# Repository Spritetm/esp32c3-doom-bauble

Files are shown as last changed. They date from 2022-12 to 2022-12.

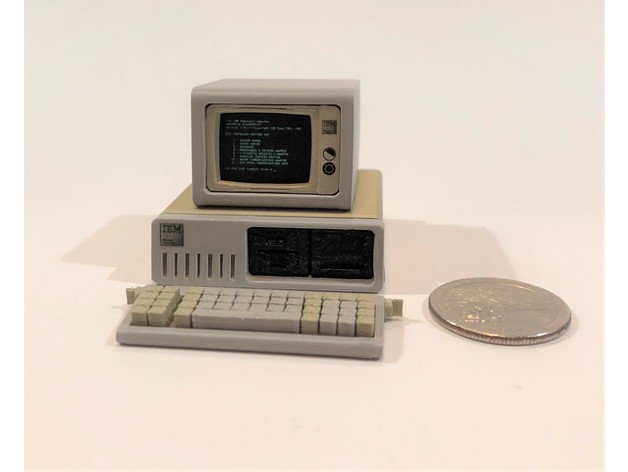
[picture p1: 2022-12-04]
case/images/pc2.jpg

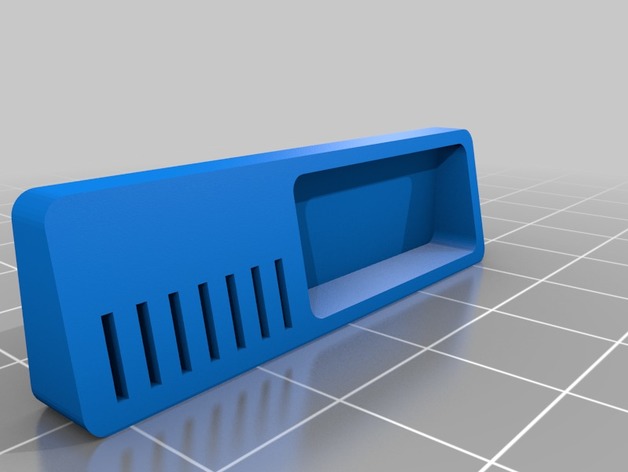
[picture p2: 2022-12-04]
case/images/01515c6048c02ab28ac9dbbb1aa9e8ba.png

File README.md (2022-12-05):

Doom on an ESP32-C3 based Christmas tree bauble
===============================================

This uses the GBA Doom from https://github.com/doomhack/GBADoom to put Doom on a tiny Christmas
bauble. More information is on https://spritesmods.com/?art=doom-bauble .

Directories
-----------

- case: contains OpenSCAD case designs. 
- esp32c3-doom: Contains the firmware. This needs ESP-IDF 5.0 or higher to compile.
- pcb - KiCad PCB designs

Case
----

You should be able to print the case on a FDM ('hot plastic squirter'-type) machine, 
but it'll look better when printed on a SLA/LCD/DLP ('ultra-violet goo hardener'-type)
printer. I masked it with masking tape afterwards and painted it with model paint
(specifically Tamiya TS-81 and TS-06 rattle-can paint).

PCB
---
The PCB designs and schematics are in Kicad format. Look at the schematics for hints 
for components not on the BOM. Note that the 'headers' on the PCB are supposed to have
wires directly soldered to it; space doesn't really allow for actual headers.

Firmware
--------

To build this, you need esp-idf 5.0 or higher. (I used git commit 4c1ff6016a, for reference.) You
also need to make sure you have 8MiB or more flash on your ESP32C3. You can use the standard 
esp-idf building & flashing procedure ('idf.py flash'). Note that you also need to flash the Doom
WAD to the flash. The flash-doom-wad.sh shellscript gives an example on how to do that with the
included doom1gba.wad file; using this will give you the shareware version of Doom (which includes
all the levels of Episode 1).

It is possible to use a different Doom WAD as a basis for this, but you need to manually convert 
it first. Tools and information for that is in the esp32c3-doom/GbaWadUtil. Most importantly, you
probably want to convert any music to IMF format and re-record demos before running GbaWadUtil
to generate the final WAD to be flashed.

Note that this Doom version is not compatible with demos that are included in existing WAD files; 
while they will play, they will likely desync early on. As such, you may want to re-record the
demo files. There's a rudimentary setup for this in esp32c3-doom/main/sdl which can be used to
compile this version of Doom for SDL input and output. After that, you can edit d_main.c and
recompile to enable demo recording of one map.

Note on input devices
---------------------

The ESP32C3 will connect to any BT-LE device that supports HID and is set to pairing mode. 
BT Classic devices aren't supported nor detected. Do note that connecting to an input 
device is not fast. Wait about 10 seconds after putting a device into pairing mode before 
using it.

Joystick has been tested and seems to work OK (although the input is digital only, no analog
movement is supported)

Mouse works, but again: inputs get flattened to digital-only. You may need a mouse 
with >=3 buttons to start the game (mouse wheel press / middle button = start)

Keyboard is implemented but entirely untested. The keymapping should be: z and x for 
shoot & open, a and s for left and right strafe, tab for select, enter for start, cursor 
keys for movement.

In general: weapon selection is hold open + use the strafe keys.

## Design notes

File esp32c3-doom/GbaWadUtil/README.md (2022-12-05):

NOTE: This has been modified for the ESP32C3 version of Doom.

Changes are that demos are replaced by the files in the 'demo' directory, and the original .mus music is replaced by the .imf equivalent in the 'music' directory.

-Sprite_tm

Original README.md:

Utility to process Doom IWAD files for GBA Doom.

It can write either a new WAD file and/or a C Source file.

This is required to reduce the memory footprint of some of the data structures in Doom to get it to fit in 256Kb.

We will pre-calculate more fields so that the lumps stored in the WAD can be used directly from the ROM rather than having to load and convert them in memory.

For example:

In the WAD file a vertex is stored as two short values. (X and Y). When it is loaded into memory, it is shifted left by 16 to convert to 16.16 fixed point. By re-writing this lump and storing it in fixed point, we do not need to copy this into memory at runtime.

Usage: GbaWadUtil -in iwad_file_path -out gba_iwad_path -cfile iwad_cfile_path.

I plan to add PWAD support so that an IWAD and 1 or more PWADS can be converted to a GBA IWAD.

It is a command line util so it can be integrated into a build process.

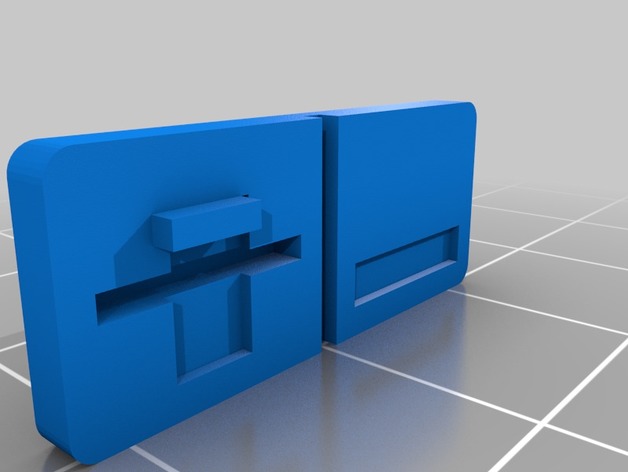
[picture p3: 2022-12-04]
case/images/93f6f09fe746f902d7aaf3ea04f6aa66.png

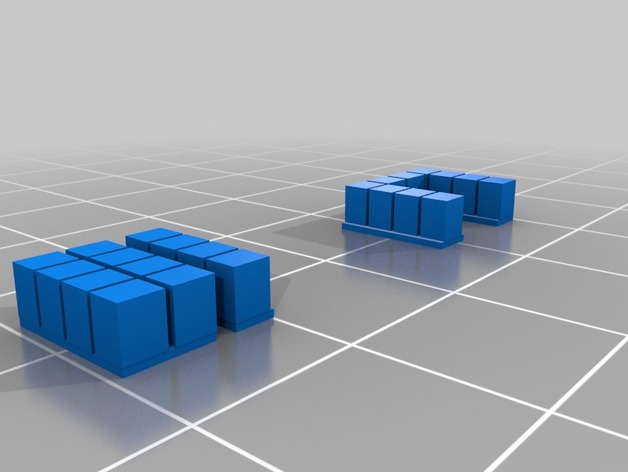
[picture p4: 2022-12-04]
case/images/9a2a5ed90a3d22a2ef03c760bfe90082.png

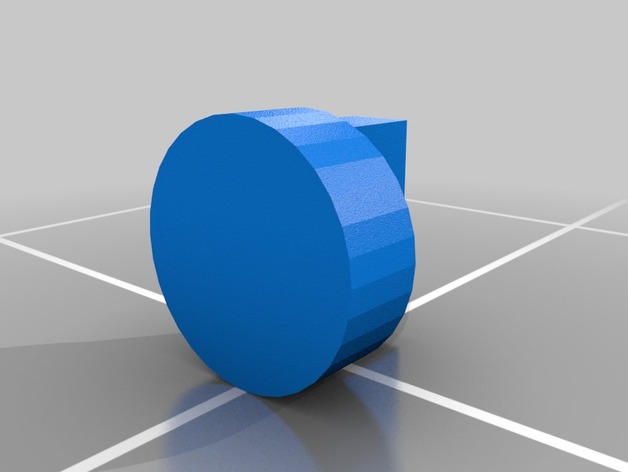
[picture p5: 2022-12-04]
case/images/41cfcd7241238f3be73395aaca2209b7.png

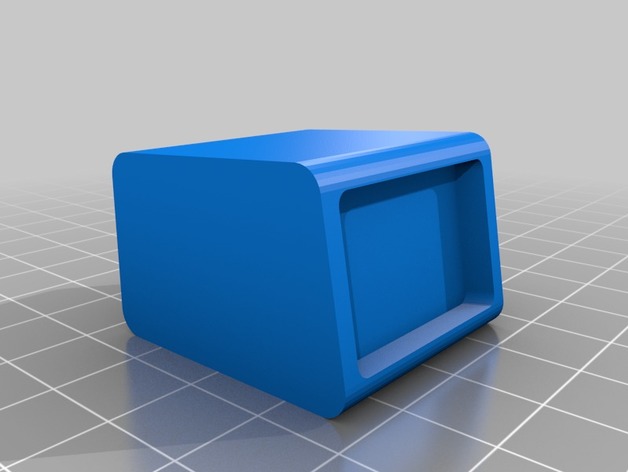
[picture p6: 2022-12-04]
case/images/0346f1c2d8671cf0db3fd7e91bc719b4.png

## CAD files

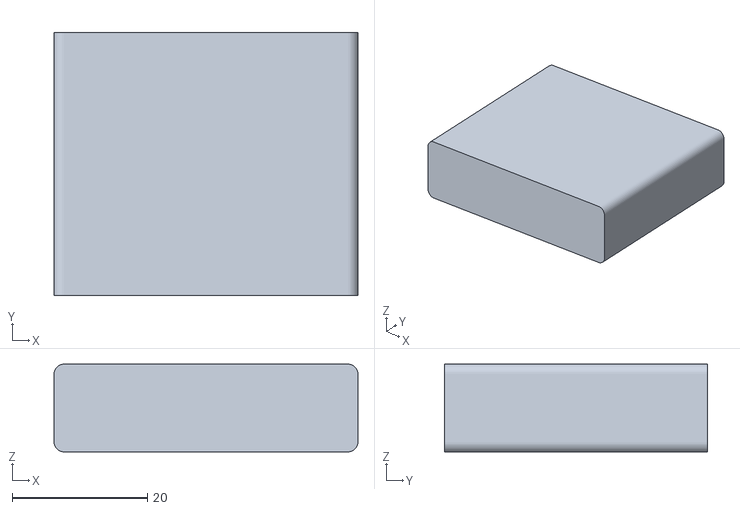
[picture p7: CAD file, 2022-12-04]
case/files/body_back.stl
45.0 x 39.0 x 13.0

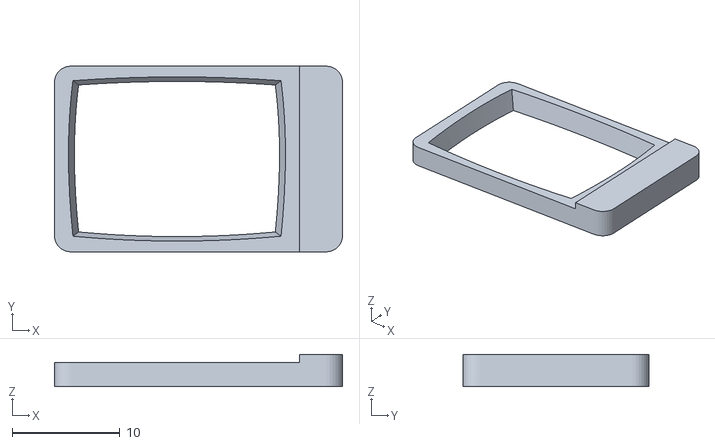
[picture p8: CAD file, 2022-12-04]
case/files/monitor_face.stl
26.8 x 17.2 x 3.00

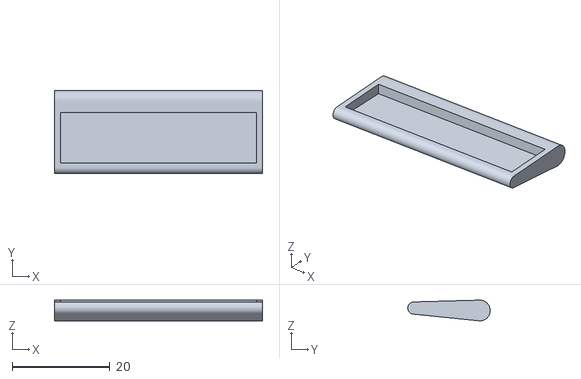
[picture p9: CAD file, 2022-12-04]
case/files/keyboard.stl
42.5 x 16.9 x 4.25

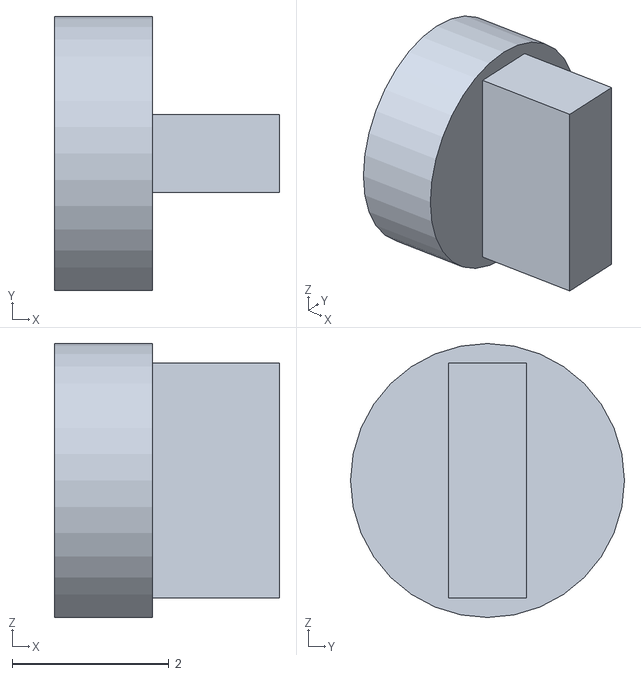
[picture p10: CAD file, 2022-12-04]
case/files/keyboard_post.stl
2.88 x 3.50 x 3.50

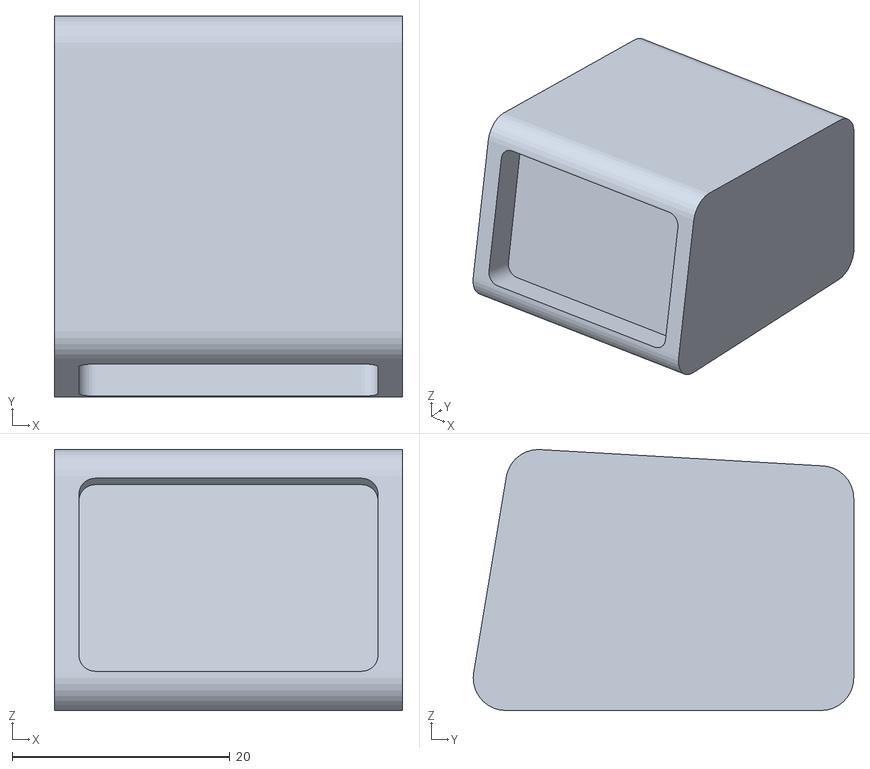
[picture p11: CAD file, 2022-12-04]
case/files/monitor.stl
32.0 x 35.0 x 24.0

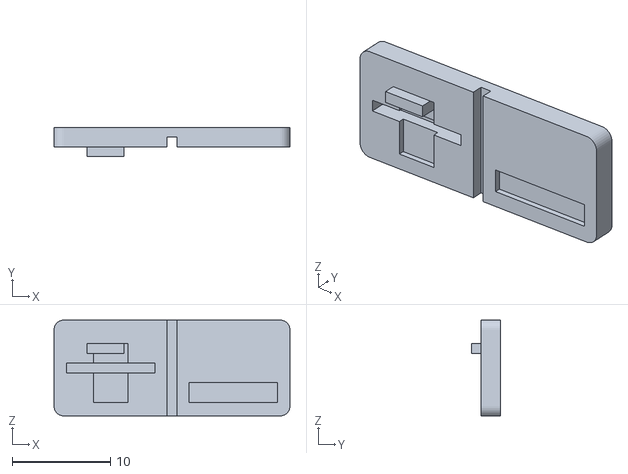
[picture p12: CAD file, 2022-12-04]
case/files/disks.stl
24.0 x 3.00 x 9.75

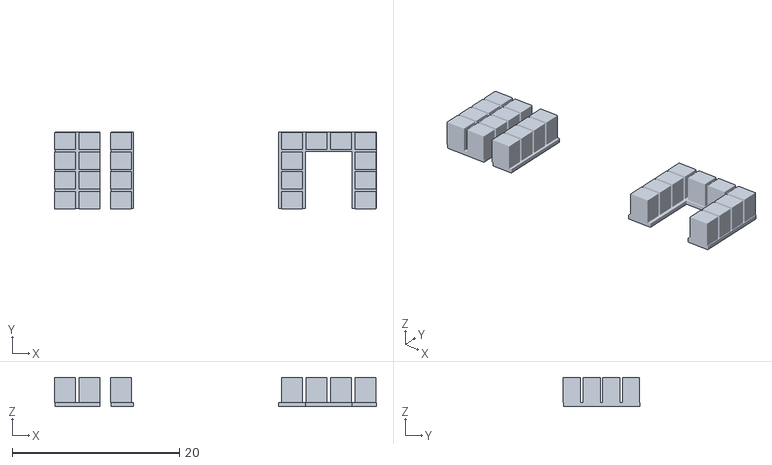
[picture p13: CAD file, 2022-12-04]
case/files/keys_grey.stl
38.5 x 9.17 x 3.50

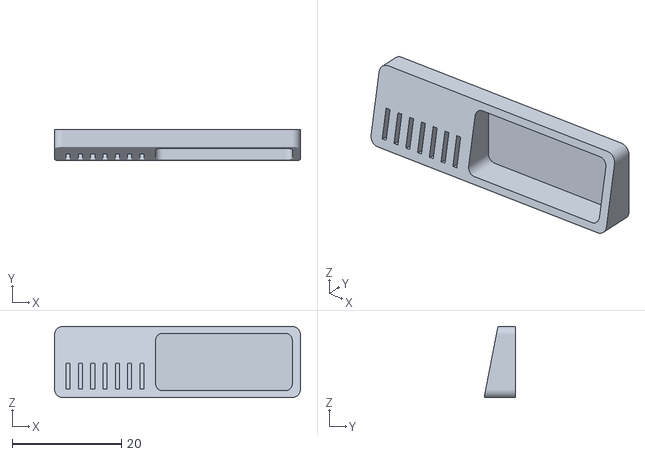
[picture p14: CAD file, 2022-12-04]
case/files/body_face.stl
45.0 x 5.75 x 13.0

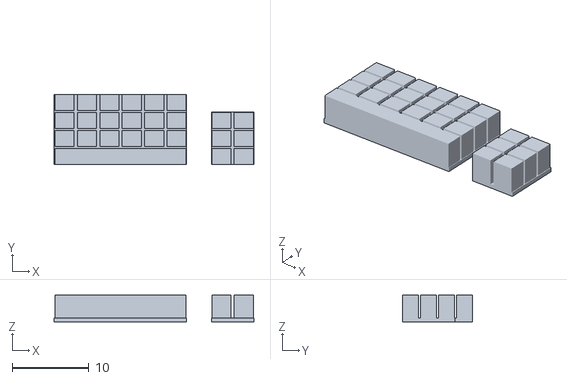
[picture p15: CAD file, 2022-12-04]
case/files/keys_white.stl
26.1 x 9.17 x 3.50

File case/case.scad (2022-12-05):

/*
 * ----------------------------------------------------------------------------
 * "THE BEER-WARE LICENSE" (Revision 42):
 * Jeroen Domburg <jeroen@spritesmods.com> wrote this file. As long as you retain 
 * this notice you can do whatever you want with this stuff. If we meet some day, 
 * and you think this stuff is worth it, you can buy me a beer in return. 
 * ----------------------------------------------------------------------------
 */

//Note that this is based on a design from RabbitEngineering: 
//https://www.thingiverse.com/thing:3331061 which is licensed under CC-BY-NC.
//Files for that are located in the files/ and images/ subdirectory. You will 
//be bound to his license (=no commercial products) as long as you use his STLs.

disp_sz=[28,13.5, 1.5];

$fa=10;
$fs=0.1;

//Enable for the main PC model
pc_model();
//Enable for the bottom plate
//translate([0,0,-3]) bot_plate();

module pokey() {
    translate([0,0,.5+0.7]) sphere(d=1.8);
    cylinder(d=1.5, h=.5+.7);
}

module bot_plate() {
    hull() {
        translate([12,12.5,-.1]) cylinder(h=0.5, d=5);
        translate([-12,12.5,-.1]) cylinder(h=0.5, d=5);
        translate([12,-11,-.1]) cylinder(h=0.5, d=5);
        translate([-12,-11,-.1]) cylinder(h=0.5, d=5);
    }
    translate([12,10,-.1]) pokey();
    translate([-12,10,-.1]) pokey();
    translate([12,-10,-.1]) pokey();
    translate([-12,-10,-.1]) pokey();

}

module pc_model() {
    difference() {
        pc();
        //lcd
    translate([5.2,-11,1]) rotate([-8,0,0]) rotate([90,-90,0]) translate([-3,0,0])cube(disp_sz+[3.2, 0.2, 0.2]);    
        //hollow out
        scale(0.73) translate([0,-0,-0.1]) cube([26,20,70], center=true);
        //air/wire line
        translate([-0.5-5,-12,-0.1]) cube([1,100,1]);
        //switch
        translate([-4.1-5, 10+1.2, -10+2])cube([8.2, 3, 10]);
        translate([-3-5, 10, -10+2])cube([6, 4.2, 10]);
        //switch pokey bit
        translate([-1.7-5, 13, -10+2])cube([3.4, 4.2, 10]);
        //usb conn
        translate([-4.1+5, 9, -10+3])cube([8.2, 7, 10]);
        //usb line
        translate([-1+5, 7, -10+1])cube([2, 7, 10]);
        //usb conn holes
        translate([5,15-1.5, -10+3-2+5]) union() {
            translate([-2.2,0,5]) cube([0.5, 1.2, 10], center=true);
            translate([2.2,0,5]) cube([0.5, 1.2, 10], center=true);
        }
        //speaker grille
        translate([7,-4,4.1]) rotate([0,90,0]) union() {
            for(i=[0:45:360]) {
                rotate([0,0,i]) translate([0,-2.3,0]) cylinder(d=1.2, h=10);
            }
            translate([0,0,0]) cylinder(d=1.2, h=10);
        }
        //speaker
        translate([4.5,-4,4.1]) hull() {
            rotate([0,90,0]) cylinder(d=8.1, h=10);
            translate([0,0,-8]) rotate([0,90,0])  cylinder(d=8.1, h=10);
        }
        //holes for bottom plate
        translate([12,10,-.1]) cylinder(h=2, d1=1.8, d2=2.1);
        translate([-12,10,-.1]) cylinder(h=2, d1=1.8, d2=2.1);
        translate([12,-10,-.1]) cylinder(h=2, d1=1.8, d2=2.1);
        translate([-12,-10,-.1]) cylinder(h=2, d1=1.8, d2=2.1);
        //cut in two
        //translate([-1000,-500,-500]) cube(1000);
    }
}


module pc() {
    scale(0.73)translate([0,0,6.4]) union() {
        import("files/body_back.stl");
        translate([0,1,0]) import("files/body_face.stl");
        translate([0,1,0]) import("files/disks.stl");
        translate([0,0,22]) import("files/monitor.stl");
        translate([0,-14,22]) rotate([80,0,0])import("files/monitor_face.stl");
        //bit between monitor and px
        translate([0,-2,10]) cube([28,28.5,7], center=true);
        //shim between face and monitor?
        translate([-14,-12.9,29.5]) cube([28,2,3]);
    }
}

//translate([5.2,-11,1]) rotate([-8,0,0]) rotate([90,-90,0]) color("red",1.0) cube(disp_sz);

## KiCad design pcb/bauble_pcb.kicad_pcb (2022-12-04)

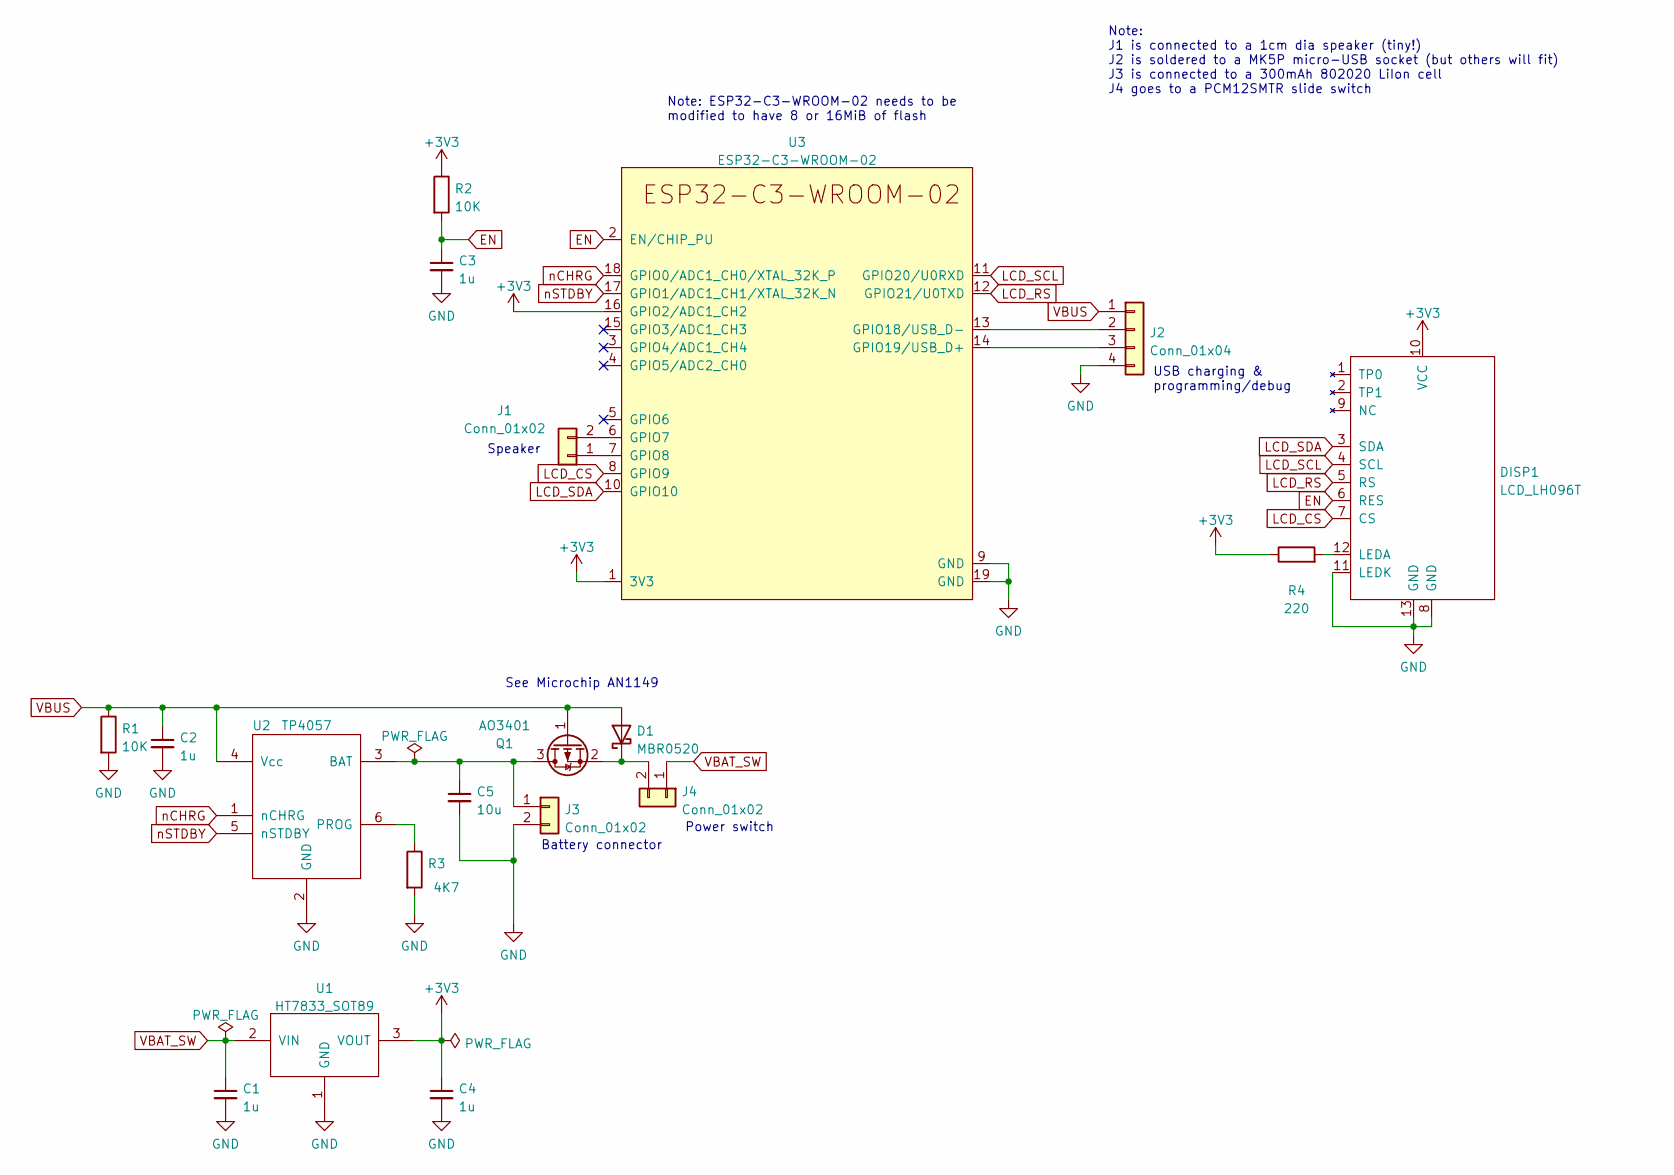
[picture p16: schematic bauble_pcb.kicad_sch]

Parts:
C1, C2, C3, C4: 1u; C_0603_1608Metric
C5: 10u; C_0805_2012Metric
D1: MBR0520; D_SOD-123
DISP1: LCD_LH096T; LCD_LH086T
J1, J3, J4: Conn_01x02; PinHeader_1x02_P1.27mm_Vertical
J2: Conn_01x04; PinHeader_1x04_P1.27mm_Vertical
Q1: AO3401; SOT-23
R1, R2: 10K; R_0603_1608Metric
R3: 4K7; R_0603_1608Metric
R4: 220; R_0603_1608Metric
U1: HT7833_SOT89; SOT-89-3
U2: TP4057; SOT-23-6
U3: ESP32-C3-WROOM-02

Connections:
+3V3: C4.1, DISP1.10 (VCC), R2.1, R4.1, U1.3 (VOUT), U3.1 (3V3), U3.16 (GPIO2/ADC1_CH2)
EN: C3.1, DISP1.6 (RES), R2.2, U3.2 (EN/CHIP_PU)
GND: C1.2, C2.2, C3.2, C4.2, C5.2, DISP1.8 (GND), DISP1.11 (LEDK), DISP1.13 (GND), J2.4, J3.2, R1.2, R3.2, U1.1 (GND), U2.2 (GND), U3.9 (GND), U3.19 (GND)
LCD_CS: DISP1.7 (CS), U3.8 (GPIO9)
LCD_RS: DISP1.5 (RS), U3.12 (GPIO21/U0TXD)
LCD_SCL: DISP1.4 (SCL), U3.11 (GPIO20/U0RXD)
LCD_SDA: DISP1.3 (SDA), U3.10 (GPIO10)
unnamed: C5.1, J3.1, Q1.3 (D), U2.3 (BAT)
unnamed: D1.1 (K), J4.2, Q1.2 (S)
unnamed: DISP1.12 (LEDA), R4.2
unnamed: J2.2, U3.13 (GPIO18/USB_D-)
unnamed: J2.3, U3.14 (GPIO19/USB_D+)
unnamed: R3.1, U2.6 (PROG)
unnamed: J1.2, U3.6 (GPIO7)
unnamed: J1.1, U3.7 (GPIO8)
VBAT_SW: C1.1, J4.1, U1.2 (VIN)
VBUS: C2.1, D1.2 (A), J2.1, Q1.1 (G), R1.1, U2.4 (Vcc)
nCHRG: U2.1 (nCHRG), U3.18 (GPIO0/ADC1_CH0/XTAL_32K_P)
nSTDBY: U2.5 (nSTDBY), U3.17 (GPIO1/ADC1_CH1/XTAL_32K_N)

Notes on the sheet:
See Microchip AN1149
Battery connector
Speaker
Note: ESP32-C3-WROOM-02 needs to be modified to have 8 or 16MiB of flash
Power switch
USB charging & programming/debug
Note: J1 is connected to a 1cm dia speaker (tiny!) J2 is soldered to a MK5P micro-USB socket (but others will fit) J3 is connected to a 300mAh 802020 LiIon cell J4 goes to a PCM12SMTR slide switch

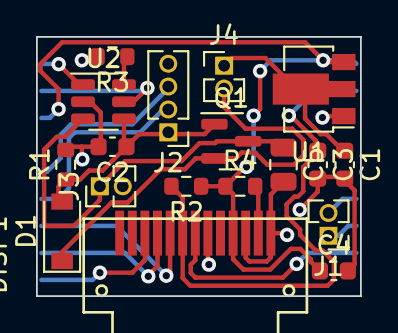
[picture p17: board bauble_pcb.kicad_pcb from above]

Board: 2 copper layers, 18.0 x 14.4 mm, 19 parts (1 on the bottom side), 19 nets.

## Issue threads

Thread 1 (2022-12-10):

Request for help with ordering on JLCPCB - Can I use PCB Assembly, and should they add edge rails and fiducials?

ndbroadbent, 2022-12-10:
Hello, thanks so much for releasing this project on GitHub, it's really cool! I would love to make one myself. I have some electronics experience and have put together some PCBs before (with through-hole components), but have never ordered anything from JLCPCB before.

I would like to use the PCB Assembly service to make things easier, but I'm seeing this error: "The PCB specs you chose are not supported for Economic PCBA"

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

I've never done any SMD soldering, but I would be happy to learn if it's the only option.

I was just curious if you were able to use PCB Assembly, or did you solder it yourself? Thanks!

Spritetm, 2022-12-10:
I have no clue... the PCB should fit the 10x10mm for economic assembly, so that should not be an issue. Perhaps it sees the ESP32C3 module on the underside and thinks it needs to do double-sided assembly, which 'economic' does not support?

The PCB thickness shouldn't really matter, but since this PCB is tiny and needs to fit in an enclosed space, I used 0.8mm PCB thickness and that works well. I soldered everything myself: the smallest component is 0603 and with a small tip and a microscope it's not that hard to get everything soldered down OK. Make sure to use enough flux, though.

ndbroadbent, 2022-12-10:
Hi @Spritetm, sorry to bother you again, but I am having a lot of trouble figuring out how to order all the components.

[I found the 0.96 Inch TFT on AliExpress.](https://www.aliexpress.com/item/32859042892.html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)

I also exported the BOM CSV from KiCad:

```
"Id";"Designator";"Package";"Quantity";"Designation";"Supplier and ref";
1;"DISP1";"LCD_LH086T";1;"LCD_LH096T";;;
2;"J4,J3,J1";"PinHeader_1x02_P1.27mm_Vertical";3;"Conn_01x02";;;
3;"U1";"SOT-89-3";1;"HT7833_SOT89";;;
4;"C3,C1,C2,C4";"C_0603_1608Metric";4;"1u";;;
5;"J2";"PinHeader_1x04_P1.27mm_Vertical";1;"Conn_01x04";;;
6;"R4";"R_0603_1608Metric";1;"220";;;
7;"R2";"R_0603_1608Metric";1;"R";;;
8;"R3";"R_0603_1608Metric";1;"2K7";;;
9;"U2";"SOT-23-6";1;"TP4057";;;
10;"C5";"C_0805_2012Metric";1;"10u";;;
11;"R1";"R_0603_1608Metric";1;"10K";;;
12;"Q1";"SOT-23";1;"AO3401";;;
13;"D1";"D_SOD-123";1;"MBR0520";;;
14;"U3";"ESP32-C3-WROOM-02";1;"ESP32-C3-WROOM-02";;;
```

I'm trying to look up these parts on Mouser or Digikey but not getting any results. For example, "HT7833". I did [find "HT7833" on the JLCPCB website](https://jlcpcb.com/partdetail/HoltekSemicon-HT7833/C50936). (Only available for PCB assembly though?)

Although I also found ["500mA LDO HT7833 SOT89" available on a website called "Best Modules Corp"](https://www.bestmodulescorp.com/ht7833-sot89.html). Is that a good site to buy from?

I was just wondering, how do you order these parts?

Spritetm, 2022-12-10:
They're mostly components I had on hand, probably ordered from LCSC at the time.

On the BOM:
- Skip J1-J4. Just solder wires directly to the holes.
- U1 - From what I can see, RT9166A-33GXL should be a replacement that Digikey at least has.
- C1-C4 - Anything 0603-sized, >=6.3V, 1uF should work
- C5 - Anything 0805-sized, >=6.3V, 10uF should work
- Whoops, R2 does not have a value. It should be 10K, same as R1.
- D1 - Any MBR05x0 in SOD123 shape should fit here
- U2 - Sorry, this needs to be a 4057. A LT4057 could technically be made to fit (you should short pin 1 and 4 in that case), but there's no direct replacement.

ndbroadbent, 2022-12-10:
Thanks a lot for your help! I figured out how to get the PCB assembly working (I had selected the purple color, and the Economic option is only available for green, blue, red, etc.)

I found [this article about how to generate the BOM and Centroid file for JLCPCB](https://support.jlcpcb.com/article/84-how-to-generate-the-bom-and-centroid-file-from-kicad). I used this plugin to generate the BOM CSV instead: [bom2grouped_csv_jlcpcb.xsl](https://gist.github.com/arturo182/a8c4a4b96907cfccf616a1edb59d0389)

I also opened the PCB and schematic in KiCad and checked the "exclude from bill of materials" for J1-J4, and also excluded the LCD and ESP32 from the BOM and position files.

Here's the updated BOM CSV using the GitHub Gist plugin:

```
Comment,Designator,Footprint,LCSC
"1u","C1,C2,C3,C4","Capacitor_SMD:C_0603_1608Metric",""
"10u","C5","Capacitor_SMD:C_0805_2012Metric",""
"MBR0520","D1","Diode_SMD:D_SOD-123",""
"AO3401","Q1","Package_TO_SOT_SMD:SOT-23",""
"10K","R1,R2","Resistor_SMD:R_0603_1608Metric",""
"4K7","R3","Resistor_SMD:R_0603_1608Metric",""
"220","R4","Resistor_SMD:R_0603_1608Metric",""
"HT7833_SOT89","U1","Package_TO_SOT_SMD:SOT-89-3",""
"TP4057","U2","Package_TO_SOT_SMD:SOT-23-6",""
```

Placement file for JLCPCB (top):

```
Designator,Val,Package,Mid X,Mid Y,Rotation,Layer
"C1","1u","C_0603_1608Metric",154.700000,-97.500000,-90.000000,top
"C2","1u","C_0603_1608Metric",141.800000,-96.500000,180.000000,top
"C3","1u","C_0603_1608Metric",153.200000,-97.500000,-90.000000,top
"C4","1u","C_0603_1608Metric",154.100000,-103.400000,0.000000,top
"C5","10u","C_0805_2012Metric",151.300000,-97.500000,-90.000000,top
"D1","MBR0520","D_SOD-123",139.000000,-101.200000,90.000000,top
"Q1","AO3401","SOT-23",148.400000,-96.200000,0.000000,top
"R1","10K","R_0603_1608Metric",139.200000,-97.500000,90.000000,top
"R2","R","R_0603_1608Metric",145.900000,-98.700000,180.000000,top
"R3","2K7","R_0603_1608Metric",141.800000,-91.500000,180.000000,top
"R4","220","R_0603_1608Metric",148.900000,-98.700000,0.000000,top
"U1","HT7833_SOT89","SOT-89-3",153.000000,-93.300000,180.000000,top
"U2","TP4057","SOT-23-6",141.300000,-94.000000,0.000000,top
```

JLCPCB was able to find all the parts:

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

The only problem is that something went wrong with generating the placement file, or maybe the import. The rotations are all off:

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

So I selected all the parts and clicked "rotate left" twice:

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

---

I placed the order and they will review it and let me know if there's an issues.

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

Thanks!!

ndbroadbent, 2022-12-10:
I finally tracked down all the other components I need (battery, speaker, switch, etc.)

From AliExpress:

* 0.96 Inch TFT screen: [FP-096H01B](https://www.aliexpress.com/item/32859042892.html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)
* Tiny speaker (<= 8.1mm diameter) - [8mm headphone speaker](https://www.aliexpress.com/item/1005003472686325.html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)
* 802020 300mAh LiIon Battery
  * Can only find [802020 250mAh](https://www.aliexpress.com/item/1005003696040249.html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)

From Mouser:

* [ESP32­-C3-­WROOM­-02U-N4](https://nz.mouser.com/ProductDetail/Espressif-Systems/ESP32-C3-WROOM-02-N4?qs=stqOd1AaK7%2FqjTZKEOgfUg%3D%3D) - $3.49
* [W25Q128JVSIQ](https://nz.mouser.com/ProductDetail/Winbond/W25Q128JVSIQ?qs=qSfuJ%252Bfl%2Fd6tLXvPR4fl9w%3D%3D) - 16MB replacement flash chip
* [Micro-USB connector](https://nz.mouser.com/ProductDetail/Molex/105164-0001?qs=JAwGc6FMfvtRY4SkW%2FoGcQ%3D%3D) (8.2mm wide)
* [Micro switch](https://nz.mouser.com/ProductDetail/Wurth-Elektronik/450404015514?qs=sPbYRqrBIVk21%2FxsES2IZA%3D%3D) (6.7mm wide)  (must be <=8.2mm wide, pins <=6mm wide)

Spritetm, 2022-12-10:
Nice! Hope you can keep us updated, it probably will make a nice recipe for others trying to build this.

ndbroadbent, 2022-12-12:
I got some feedback from JLC about the 3D model:

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

----

@Spritetm Did you get a similar response from JLC?

I was able to fix the speaker grill holes to be 1.5mm:

```diff
         }
         //speaker grille
-        translate([7,-4,4.1]) rotate([0,90,0]) union() {
+        translate([7,-4,4.4]) rotate([0,90,0]) union() {
             for(i=[0:45:360]) {
-                rotate([0,0,i]) translate([0,-2.3,0]) cylinder(d=1.2, h=10);
+                rotate([0,0,i]) translate([0,-2.5,0]) cylinder(d=1.5, h=10);
             }
-            translate([0,0,0]) cylinder(d=1.2, h=10);
+            translate([0,0,0]) cylinder(d=1.5, h=10);
         }
         //speaker
         translate([4.5,-4,4.1]) hull() {
```

But I might need to open some of the STLs in Blender and see if I can fix the thin walls

Spritetm, 2022-12-12:
I think I got a similar warning from JLC (but mine was automated, seems the Chinese version differs a bit from the international version) and I just YOLO'ed it. The worst bit of thin wall is behind the top of the LCD, so if that breaks through it's not visible from the outside. The holes aren't critical; they worked pretty well for me but if they clogged I would have run them through with a drill to clean them up.

computerhac, 2023-01-10:
So I ordered some PCBs with the above BOM and placement corrections. I tried two with the memory upgrade and one without. All 3 when hooked to usb boot loop. Or, perhaps more accurately, the serial device becomes available then unavailable in a loop. I have tried with and without a battery. even flipped U2 in case that was incorrect. Has anyone else experienced this? Any ideas what's going on?

Spritetm, 2023-01-10:
The C3 does that when it's not programmed. Simplest solution is to ground GPIO9 when applying power (using either something like a pair of tweezers or a temporary bodge wire) and retry programming.

computerhac, 2023-01-10:
Here I am trying to track down an electronics issue and I just needed to press the program button. Thank you for the quick reply! Cool project BTW

computerhac, 2023-01-12:
Just as a note for anyone who builds with the bom above, the LCD colors are inverted as is.

In main>lcd.c under Rcmd1 I had to change ST77XX_INVON , 0 to ST77XX_INVOFF , 0

xenical1212, 2023-04-08:
does anyone have any of the boom or cpl working file for the pcb i cant seem to get the generators to work

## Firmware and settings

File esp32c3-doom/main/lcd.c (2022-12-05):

/*
 * ----------------------------------------------------------------------------
 * "THE BEER-WARE LICENSE" (Revision 42):
 * Jeroen Domburg <jeroen@spritesmods.com> wrote this file. As long as you retain 
 * this notice you can do whatever you want with this stuff. If we meet some day, 
 * and you think this stuff is worth it, you can buy me a beer in return. 
 * ----------------------------------------------------------------------------
 */
#include <stdio.h>
#include <stdlib.h>
#include <string.h>
#include "freertos/FreeRTOS.h"
#include "freertos/task.h"
#include "freertos/semphr.h"
#include "esp_system.h"
#include "driver/spi_master.h"
#include "driver/gpio.h"
#include "io.h"

#define LCD_YOFF 3

#define PIN_NUM_MISO -1
#define PIN_NUM_MOSI IO_LCD_MOSI
#define PIN_NUM_CLK	 IO_LCD_CLK
#define PIN_NUM_CS	 IO_LCD_CS

#define PIN_NUM_DC	 IO_LCD_DC
#define PIN_NUM_RST	 -1
#define PIN_NUM_BCKL -1

#define PARALLEL_LINES 4

#define ST7735_MADCTL_BGR 0x08
#define ST7735_MADCTL_MH  0x04

#define ST7735_FRMCTR1 0xB1
#define ST7735_FRMCTR2 0xB2
#define ST7735_FRMCTR3 0xB3
#define ST7735_INVCTR  0xB4
#define ST7735_DISSET5 0xB6

#define ST7735_PWCTR1  0xC0
#define ST7735_PWCTR2  0xC1
#define ST7735_PWCTR3  0xC2
#define ST7735_PWCTR4  0xC3
#define ST7735_PWCTR5  0xC4
#define ST7735_VMCTR1  0xC5

#define ST7735_PWCTR6  0xFC

#define ST7735_GMCTRP1 0xE0
#define ST7735_GMCTRN1 0xE1

#define ST_CMD_DELAY   0x80	   // special signifier for command lists

#define ST77XX_NOP	   0x00
#define ST77XX_SWRESET 0x01
#define ST77XX_RDDID   0x04
#define ST77XX_RDDST   0x09

#define ST77XX_SLPIN   0x10
#define ST77XX_SLPOUT  0x11
#define ST77XX_PTLON   0x12
#define ST77XX_NORON   0x13

#define ST77XX_INVOFF  0x20
#define ST77XX_INVON   0x21
#define ST77XX_DISPOFF 0x28
#define ST77XX_DISPON  0x29
#define ST77XX_CASET   0x2A
#define ST77XX_RASET   0x2B
#define ST77XX_RAMWR   0x2C
#define ST77XX_RAMRD   0x2E

#define ST77XX_PTLAR   0x30
#define ST77XX_COLMOD  0x3A
#define ST77XX_MADCTL  0x36

#define ST77XX_MADCTL_MY  0x80
#define ST77XX_MADCTL_MX  0x40
#define ST77XX_MADCTL_MV  0x20
#define ST77XX_MADCTL_ML  0x10
#define ST77XX_MADCTL_RGB 0x00

#define ST77XX_RDID1   0xDA
#define ST77XX_RDID2   0xDB
#define ST77XX_RDID3   0xDC
#define ST77XX_RDID4   0xDD


static const uint8_t
  Bcmd[] = {				  // Initialization commands for 7735B screens
	18,						  // 18 commands in list:
	ST77XX_SWRESET,	  ST_CMD_DELAY,	 //	 1: Software reset, no args, w/delay
	  50,					  //	 50 ms delay
	ST77XX_SLPOUT ,	  ST_CMD_DELAY,	 //	 2: Out of sleep mode, no args, w/delay
	  255,					  //	 255 = 500 ms delay
	ST77XX_COLMOD , 1+ST_CMD_DELAY,	 //	 3: Set color mode, 1 arg + delay:
	  0x05,					  //	 16-bit color
	  10,					  //	 10 ms delay
	ST7735_FRMCTR1, 3+ST_CMD_DELAY,	 //	 4: Frame rate control, 3 args + delay:
	  0x00,					  //	 fastest refresh
	  0x06,					  //	 6 lines front porch
	  0x03,					  //	 3 lines back porch
	  10,					  //	 10 ms delay
	ST77XX_MADCTL , 1	   ,  //  5: Memory access ctrl (directions), 1 arg:
	  0x08,					  //	 Row addr/col addr, bottom to top refresh
	ST7735_DISSET5, 2	   ,  //  6: Display settings #5, 2 args, no delay:
	  0x15,					  //	 1 clk cycle nonoverlap, 2 cycle gate
							  //	 rise, 3 cycle osc equalize
	  0x02,					  //	 Fix on VTL
	ST7735_INVCTR , 1	   ,  //  7: Display inversion control, 1 arg:
	  0x0,					  //	 Line inversion
	ST7735_PWCTR1 , 2+ST_CMD_DELAY,	 //	 8: Power control, 2 args + delay:
	  0x02,					  //	 GVDD = 4.7V
	  0x70,					  //	 1.0uA
	  10,					  //	 10 ms delay
	ST7735_PWCTR2 , 1	   ,  //  9: Power control, 1 arg, no delay:
	  0x05,					  //	 VGH = 14.7V, VGL = -7.35V
	ST7735_PWCTR3 , 2	   ,  // 10: Power control, 2 args, no delay:
	  0x01,					  //	 Opamp current small
	  0x02,					  //	 Boost frequency
	ST7735_VMCTR1 , 2+ST_CMD_DELAY,	 // 11: Power control, 2 args + delay:
	  0x3C,					  //	 VCOMH = 4V
	  0x38,					  //	 VCOML = -1.1V
	  10,					  //	 10 ms delay
	ST7735_PWCTR6 , 2	   ,  // 12: Power control, 2 args, no delay:
	  0x11, 0x15,
	ST7735_GMCTRP1,16	   ,  // 13: Magical unicorn dust, 16 args, no delay:
	  0x09, 0x16, 0x09, 0x20, //	 (seriously though, not sure what
	  0x21, 0x1B, 0x13, 0x19, //	  these config values represent)
	  0x17, 0x15, 0x1E, 0x2B,
	  0x04, 0x05, 0x02, 0x0E,
	ST7735_GMCTRN1,16+ST_CMD_DELAY,	 // 14: Sparkles and rainbows, 16 args + delay:
	  0x0B, 0x14, 0x08, 0x1E, //	 (ditto)
	  0x22, 0x1D, 0x18, 0x1E,
	  0x1B, 0x1A, 0x24, 0x2B,
	  0x06, 0x06, 0x02, 0x0F,
	  10,					  //	 10 ms delay
	ST77XX_CASET  , 4	   ,  // 15: Column addr set, 4 args, no delay:
	  0x00, 0x02,			  //	 XSTART = 2
	  0x00, 0x81,			  //	 XEND = 129
	ST77XX_RASET  , 4	   ,  // 16: Row addr set, 4 args, no delay:
	  0x00, 0x02,			  //	 XSTART = 1
	  0x00, 0x81,			  //	 XEND = 160
	ST77XX_NORON  ,	  ST_CMD_DELAY,	 // 17: Normal display on, no args, w/delay
	  10,					  //	 10 ms delay
	ST77XX_DISPON ,	  ST_CMD_DELAY,	 // 18: Main screen turn on, no args, w/delay
	  255 },				  //	 255 = 500 ms delay
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

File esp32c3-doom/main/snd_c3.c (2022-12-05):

/*
 * ----------------------------------------------------------------------------
 * "THE BEER-WARE LICENSE" (Revision 42):
 * Jeroen Domburg <jeroen@spritesmods.com> wrote this file. As long as you retain 
 * this notice you can do whatever you want with this stuff. If we meet some day, 
 * and you think this stuff is worth it, you can buy me a beer in return. 
 * ----------------------------------------------------------------------------
 */

#include <stdio.h>
#include <stdlib.h>
#include <string.h>
#include "freertos/FreeRTOS.h"
#include "freertos/task.h"
#include "freertos/queue.h"
#include "esp_system.h"
#include "driver/gpio.h"
#include <stdint.h>
#include "assert.h"
#include "snd_c3.h"
#include "driver/i2s_pdm.h"
#include "soc/gpio_sig_map.h"
#include "esp_log.h"

const char *TAG="sndc3";

#define BUFSZ 128

static snd_cb_t *snd_cb;
i2s_chan_handle_t i2s_handle;

void snd_task(void *arg) {
	int16_t buf[BUFSZ];
	while(1) {
		snd_cb(buf, BUFSZ);
		size_t written=0;
		ESP_ERROR_CHECK(i2s_channel_write(i2s_handle, buf, BUFSZ*2, &written, 1000));
	}
}

void snd_init(int samprate, snd_cb_t *cb, int pin_a, int pin_b) {
	snd_cb=cb;

	i2s_chan_config_t i2s_config={
		.id=0,
		.role=I2S_ROLE_MASTER,
		.dma_desc_num=2,
		.dma_frame_num=128,
		.auto_clear=true
	};
	ESP_ERROR_CHECK(i2s_new_channel(&i2s_config, &i2s_handle, NULL));
	
	i2s_pdm_tx_config_t i2s_pdm_config={
		.clk_cfg=I2S_PDM_TX_CLK_DEFAULT_CONFIG(samprate),
		.slot_cfg=I2S_PDM_TX_SLOT_DEFAULT_CONFIG(I2S_DATA_BIT_WIDTH_16BIT, I2S_SLOT_MODE_MONO),
		.gpio_cfg={
			.clk=GPIO_NUM_NC,
			.dout=pin_a,
		}
	};
	
	ESP_ERROR_CHECK(i2s_channel_init_pdm_tx_mode(i2s_handle, &i2s_pdm_config));
	i2s_channel_enable(i2s_handle);

	//Start task to handle sound stuff
	xTaskCreate(snd_task, "snd", 2*1024, NULL, 5, NULL);

	vTaskDelay(pdMS_TO_TICKS(200));

	//GPIO1 is the inverse of GPIO0
	esp_rom_gpio_connect_out_signal(pin_b, I2SO_SD_OUT_IDX, 1, 0);
	gpio_set_drive_capability(pin_a, GPIO_DRIVE_CAP_3);
	gpio_set_drive_capability(pin_b, GPIO_DRIVE_CAP_3);
}

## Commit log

2021-07-03 Initial commit. Plays to serial console.
    [partitions.csv]
2021-07-04 Opl3 emulation... this one seems too slow.
    [snd_c3.c]
2022-11-13 omg bt input works kinda, needs some work
    [partitions.csv]
2022-11-15 Fix for audio volume, js
    [snd_c3.c]
2022-12-04 Add other files; add preliminary support for mouse and keyboard
    [bauble_pcb-B_Cu.gbr, bauble_pcb-B_Mask.gbr, bauble_pcb-B_Paste.gbr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]
2022-12-05 Cleanup, add licenses to some files
    [case.scad, case.stl]
